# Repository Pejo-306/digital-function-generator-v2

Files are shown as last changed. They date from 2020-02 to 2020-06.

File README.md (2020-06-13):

# Цифров генератор на сигнали с тъчскрийн

Генератор на сигнали, реализиран на принципа на Директния Цифров Синтез (DDS).
Проектът е разработен като дипломна работа в 12-ти клас, ТУЕС.

## Съдържание

* [Кратко описание](#кратко-описание)
* [Документация](#документация)
* [Инсталиране на управляващия софтуер](#инсталиране-на-управляващия-софтуер)
* [Лиценз](#лиценз)

## Кратко описание

Генераторите на сигнали са изключително полезни лабораторни инструменти за
изследване на други електронни устройства или части от тях. Инструментите се
използват за възпроизвеждане на най-различни електрически сигнали, които служат
като входни сигнали за други устройства.

Цифровите генератори на сигнали са mixed-signal устройства (включват и аналогова,
и цифрова схемотехника, като и двете функционират ръка за ръка), реализирани
посредством DDS система. Тези генератори, както и разработеният за тази дипломна
работа, имат следните възможностти:
- възпроизвеждане на сигнали с произволна форма;
- регулиране на амплитудата на сигнали;
- добавяне на постояннотоково отместване към генерирания сигнал;
- настройване на честотата на сигнала.

Освен това разработеното за дипломната работа устройство използва течнокристален
екран с панел за допир за реализиране на потребителския си интерфейс. По-подробно
описание на употребения тъчскрийн модул може да бъде намерено [тук](http://www.lcdwiki.com/3.2inch_SPI_Module_ILI9341_SKU:MSP3218).

## Документация

Подробна документация на дипломната работа, написана на български език, може да
бъде намерена [тук](docs/bg/Diploma%20Work_Petar%20Nikolov_2020-bg.pdf).

## Инсталиране на управляващия софтуер

Управляващият софтуер е написан на езика *AVR-C* и е разработен за
микроконтролери от серията *ATmega2561*. Освен това софтуерният проект се 
управлява с конзолната програма **make**.

Първоначално е необходимо да се дръпне проекта от GitHub и да се навигира
до папката, съдържаща софтуерния проект:

```bash
$ git clone https://github.com/Pejo-306/digital-function-generator-v2.git
$ cd digital-function-generator-v2/software/DFGv2-Firmware.X/
```

Проектът се компилира с **make** програмата:

```bash
$ make build
```

След това е необходимо да се свърже подходящ програматор към *ATmega2561* и да
се запише управляващата програма в програмната флаш памет на микроконтролера:

```bash
$ make flash
```

Също така е необходимо да се конфигурират определени хардуерни настройки на
*ATmega2561*:

```bash
$ make fuse
```

## Лиценз

Този проект се разпространява с [MIT лиценз](LICENSE).

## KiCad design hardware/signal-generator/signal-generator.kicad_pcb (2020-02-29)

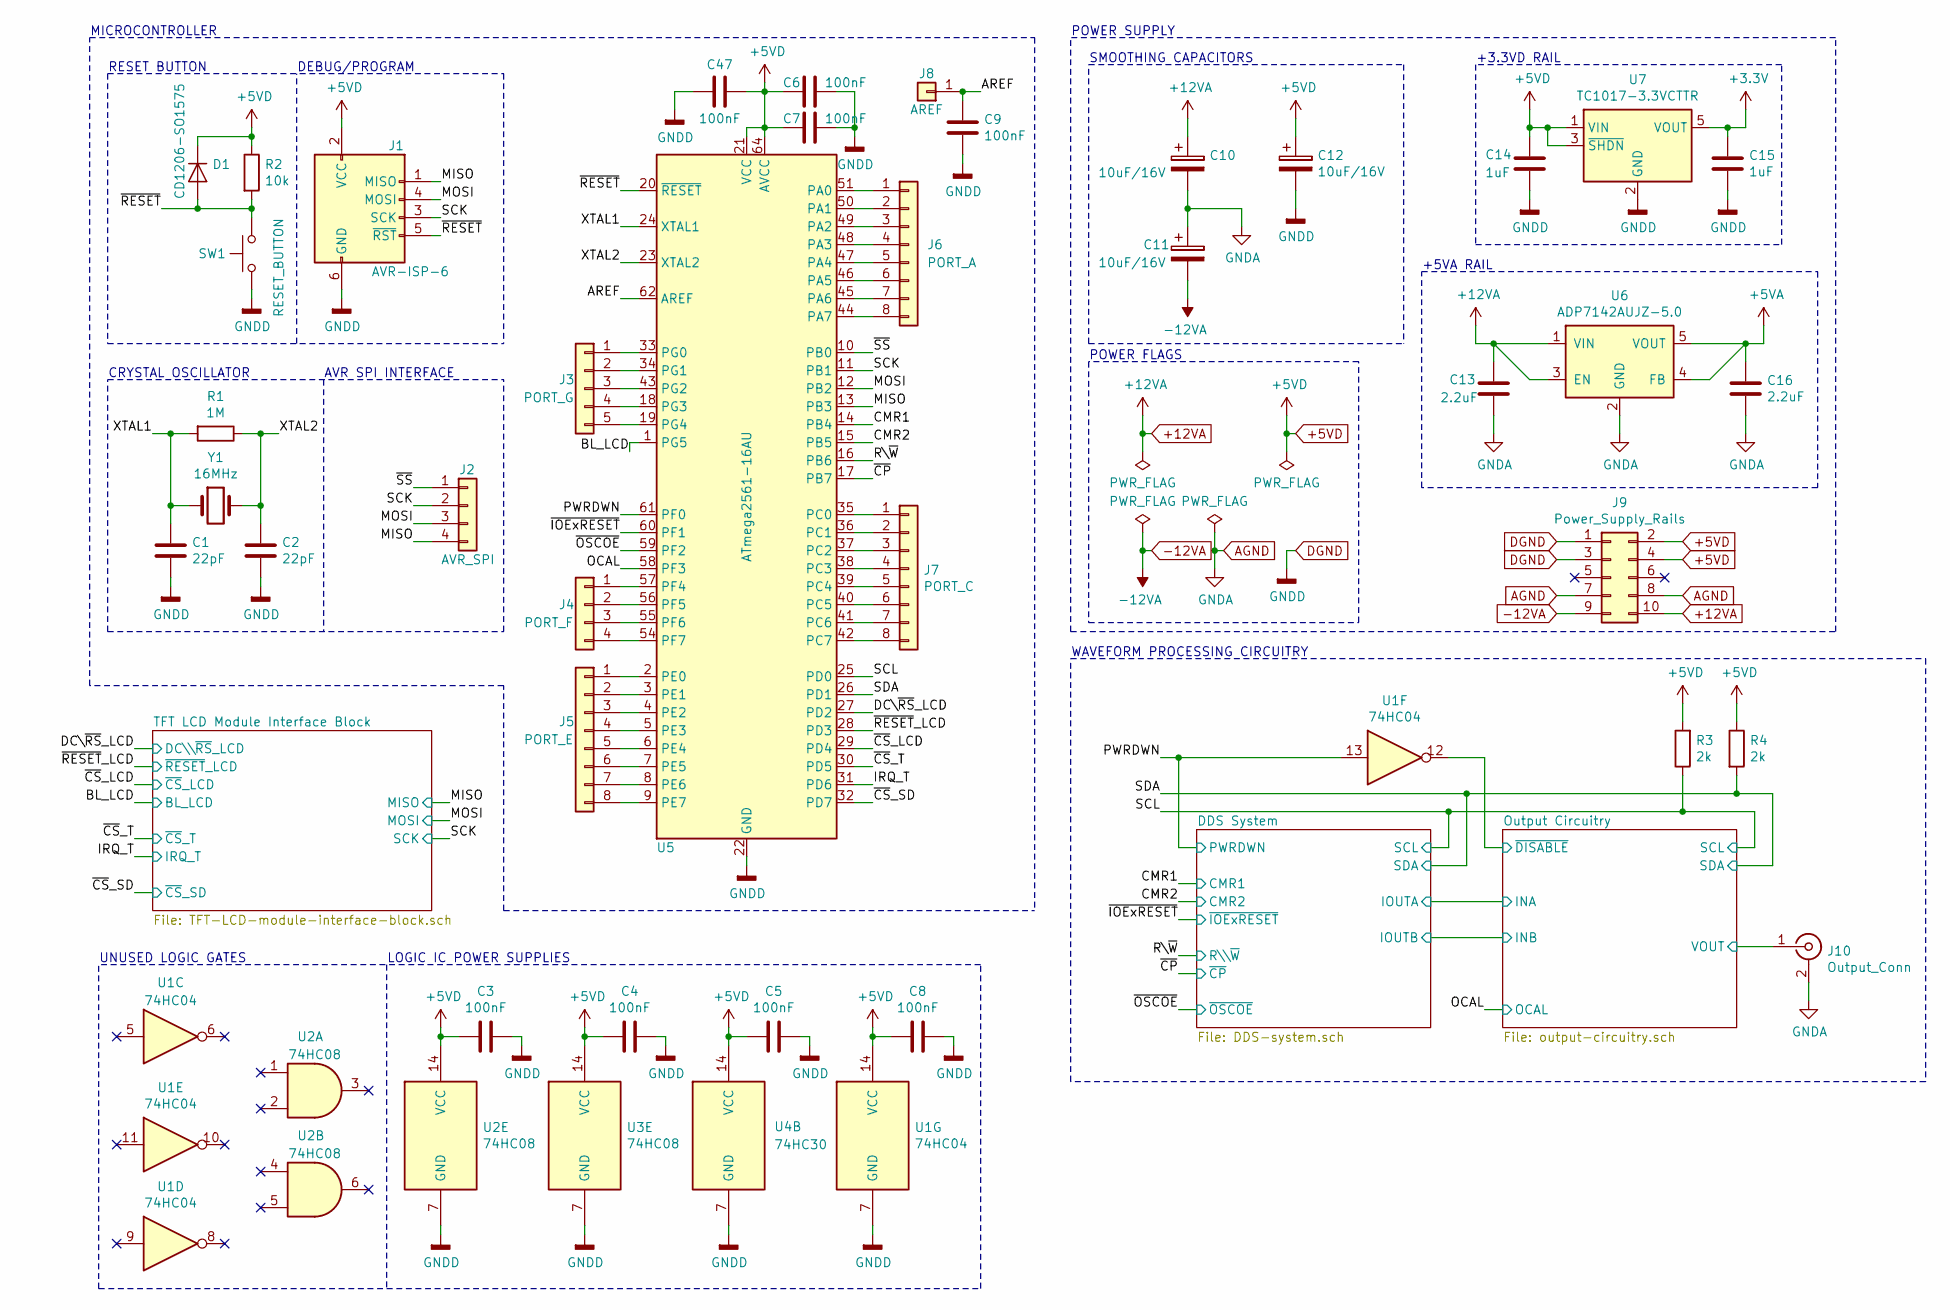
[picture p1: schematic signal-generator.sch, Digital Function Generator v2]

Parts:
C1, C2: 22pF; C_0805_HandSoldering
C3, C4, C5, C6, C7, C8, C9, C47: 100nF; C_0805_HandSoldering
C10, C11, C12: 10uF/16V; CP_Elec_4x5.3
C13, C16: 2.2uF; C_0805_HandSoldering
C14, C15: 1uF; C_0805_HandSoldering
D1: CD1206-SO1575; D_1206
J1: AVR-ISP-6; Pin_Header_Straight_2x03_Pitch2.54mm
J2: AVR_SPI; Pin_Header_Straight_1x04_Pitch2.54mm
J3: PORT_G; Pin_Header_Straight_1x05_Pitch2.54mm
J4: PORT_F; Pin_Header_Straight_1x04_Pitch2.54mm
J5: PORT_E; Pin_Header_Straight_1x08_Pitch2.54mm
J6: PORT_A; Pin_Header_Straight_1x08_Pitch2.54mm
J7: PORT_C; Pin_Header_Straight_1x08_Pitch2.54mm
J8: AREF; Pin_Header_Straight_1x01_Pitch2.54mm
J9: Power_Supply_Rails; Pin_Header_Straight_2x05_Pitch2.54mm
J10: Output_Conn; BNC_Socket_TYCO-AMP
R1: 1M; R_1206_HandSoldering
R2: 10k; R_0805_HandSoldering
R3, R4: 2k; R_0805_HandSoldering
SW1: RESET_BUTTON; SW_PUSH_6mm_h4.3mm
U1: 74HC04; SOIC-14_3.9x8.7mm_Pitch1.27mm
U2, U3: 74HC08; SOIC-14_3.9x8.7mm_Pitch1.27mm
U4: 74HC30; SOIC-14_3.9x8.7mm_Pitch1.27mm
U5: ATmega2561-16AU; TQFP-64_14x14mm_Pitch0.8mm
U6: ADP7142AUJZ-5.0; TSOT-23-5_HandSoldering
U7: TC1017-3.3VCTTR; SOT-23-5_HandSoldering
Y1: 16MHz; Crystal_HC49-U_Vertical

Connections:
+3V3: C15.1, U7.5 (VOUT); also elsewhere on the board
+5VA: C16.1, U6.4 (FB), U6.5 (VOUT); also elsewhere on the board
+12VA: C10.1, C13.1, J9.10, U6.1 (VIN), U6.3 (EN); also elsewhere on the board
-12VA: C11.2, J9.9; also elsewhere on the board
/AREF: C9.1, J8.1, U5.62 (AREF)
/BL_LCD: U5.1 (PG5); also elsewhere on the board
/DC\~RS~_LCD: U5.27 (PD2); also elsewhere on the board
/IRQ_T: U5.31 (PD6); also elsewhere on the board
/MISO: J1.1 (MISO), J2.4, U5.13 (PB3); also elsewhere on the board
/MOSI: J1.4 (MOSI), J2.3, U5.12 (PB2); also elsewhere on the board
/OCAL: U5.58 (PF3); also elsewhere on the board
/Output Circuitry/VOUT: J10.1 (In); also elsewhere on the board
/Output Circuitry/~DISABLE: U1.12; also elsewhere on the board
/PWRDWN: U1.13, U5.61 (PF0); also elsewhere on the board
/R\~W: U5.16 (PB6); also elsewhere on the board
/SCK: J1.3 (SCK), J2.2, U5.11 (PB1); also elsewhere on the board
/SCL: R3.1, U5.25 (PD0); also elsewhere on the board
/SDA: R4.2, U5.26 (PD1); also elsewhere on the board
/XTAL1: C1.1, R1.2, U5.24 (XTAL1), Y1.1
/XTAL2: C2.1, R1.1, U5.23 (XTAL2), Y1.2
/~CMR1: U5.14 (PB4); also elsewhere on the board
/~CMR2: U5.15 (PB5); also elsewhere on the board
/~CP: U5.17 (PB7); also elsewhere on the board
/~CS~_LCD: U5.29 (PD4); also elsewhere on the board
/~CS~_SD: U5.32 (PD7); also elsewhere on the board
/~CS~_T: U5.30 (PD5); also elsewhere on the board
/~IOExRESET: U5.60 (PF1); also elsewhere on the board
/~OSCOE: U5.59 (PF2); also elsewhere on the board
/~RESET: D1.2 (A), J1.5 (~RST), R2.2, SW1.2, U5.20 (~RESET)
/~RESET~_LCD: U5.28 (PD3); also elsewhere on the board
/~SS: J2.1, U5.10 (PB0)
unnamed: J3.1, U5.33 (PG0)
unnamed: J3.2, U5.34 (PG1)
unnamed: J3.3, U5.43 (PG2)
unnamed: J3.4, U5.18 (PG3)
unnamed: J3.5, U5.19 (PG4)
unnamed: J4.1, U5.57 (PF4)
unnamed: J4.2, U5.56 (PF5)
unnamed: J4.3, U5.55 (PF6)
unnamed: J4.4, U5.54 (PF7)
unnamed: J5.1, U5.2 (PE0)
unnamed: J5.2, U5.3 (PE1)
unnamed: J5.3, U5.4 (PE2)
unnamed: J5.4, U5.5 (PE3)
unnamed: J5.5, U5.6 (PE4)
unnamed: J5.6, U5.7 (PE5)
unnamed: J5.7, U5.8 (PE6)
unnamed: J5.8, U5.9 (PE7)
unnamed: J6.1, U5.51 (PA0)
unnamed: J6.2, U5.50 (PA1)
unnamed: J6.3, U5.49 (PA2)
unnamed: J6.4, U5.48 (PA3)
unnamed: J6.5, U5.47 (PA4)
unnamed: J6.6, U5.46 (PA5)
unnamed: J6.7, U5.45 (PA6)
unnamed: J6.8, U5.44 (PA7)
unnamed: J7.1, U5.35 (PC0)
unnamed: J7.2, U5.36 (PC1)
unnamed: J7.3, U5.37 (PC2)
unnamed: J7.4, U5.38 (PC3)
unnamed: J7.5, U5.39 (PC4)
unnamed: J7.6, U5.40 (PC5)
unnamed: J7.7, U5.41 (PC6)
unnamed: J7.8, U5.42 (PC7)

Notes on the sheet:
POWER FLAGS
SMOOTHING CAPACITORS
+5VA RAIL
POWER SUPPLY
RESET BUTTON
DEBUG/PROGRAM
CRYSTAL OSCILLATOR
+3.3VD RAIL
AVR SPI INTERFACE
MICROCONTROLLER
WAVEFORM PROCESSING CIRCUITRY
LOGIC IC POWER SUPPLIES
UNUSED LOGIC GATES

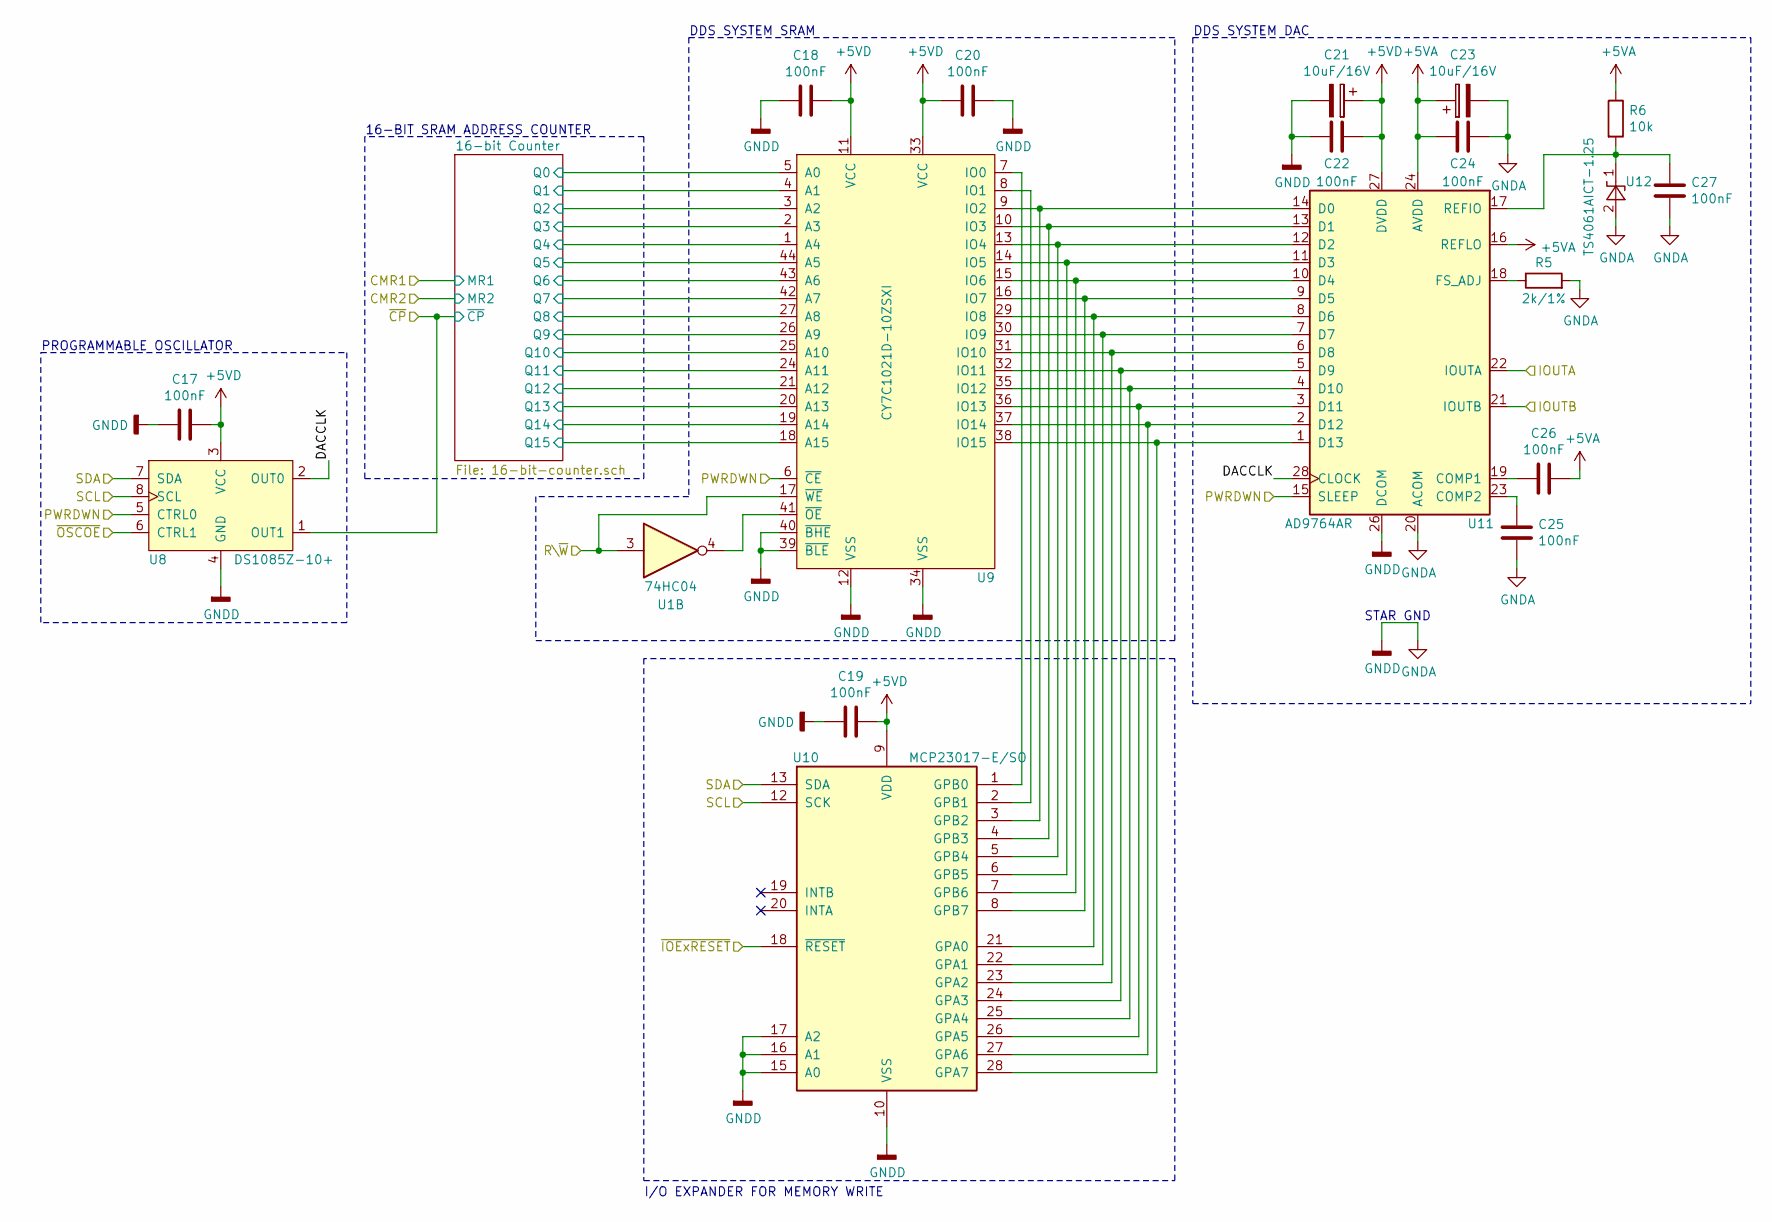
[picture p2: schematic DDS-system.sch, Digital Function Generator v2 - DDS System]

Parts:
C17, C18, C19, C20, C22, C24, C25, C26, C27: 100nF; C_0805_HandSoldering
C21, C23: 10uF/16V; CP_Tantalum_Case-A_EIA-3216-18_Hand
R5: 2k/1%; R_0805_HandSoldering
R6: 10k; R_0805_HandSoldering
U1: 74HC04; SOIC-14_3.9x8.7mm_Pitch1.27mm
U8: DS1085Z-10+; SOIC-8_3.9x4.9mm_Pitch1.27mm
U9: CY7C1021D-10ZSXI; SOP80P1176X120-44N
U10: MCP23017-E/SO; SOIC-28W_7.5x17.9mm_Pitch1.27mm
U11: AD9764AR; SOIC-28W_7.5x17.9mm_Pitch1.27mm
U12: TS4061AICT-1.25; SOT-323_SC-70_Handsoldering

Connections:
+5VA: C23.1, C24.2, C26.1, R6.1, U11.16 (REFLO), U11.24 (AVDD); also elsewhere on the board
/DDS System/16-bit Counter/Q0: U9.5 (A0); also elsewhere on the board
/DDS System/16-bit Counter/Q1: U9.4 (A1); also elsewhere on the board
/DDS System/16-bit Counter/Q2: U9.3 (A2); also elsewhere on the board
/DDS System/16-bit Counter/Q3: U9.2 (A3); also elsewhere on the board
/DDS System/16-bit Counter/Q4: U9.1 (A4); also elsewhere on the board
/DDS System/16-bit Counter/Q5: U9.44 (A5); also elsewhere on the board
/DDS System/16-bit Counter/Q6: U9.43 (A6); also elsewhere on the board
/DDS System/16-bit Counter/Q7: U9.42 (A7); also elsewhere on the board
/DDS System/16-bit Counter/Q8: U9.27 (A8); also elsewhere on the board
/DDS System/16-bit Counter/Q9: U9.26 (A9); also elsewhere on the board
/DDS System/16-bit Counter/Q10: U9.25 (A10); also elsewhere on the board
/DDS System/16-bit Counter/Q11: U9.24 (A11); also elsewhere on the board
/DDS System/16-bit Counter/Q12: U9.21 (A12); also elsewhere on the board
/DDS System/16-bit Counter/Q13: U9.20 (A13); also elsewhere on the board
/DDS System/16-bit Counter/Q14: U9.19 (A14); also elsewhere on the board
/DDS System/16-bit Counter/Q15: U9.18 (A15); also elsewhere on the board
/DDS System/DACCLK: U8.2 (OUT0), U11.28 (CLOCK)
/Output Circuitry/INA: U11.22 (IOUTA); also elsewhere on the board
/Output Circuitry/INB: U11.21 (IOUTB); also elsewhere on the board
/PWRDWN: U8.5 (CTRL0), U9.6 (~CE), U11.15 (SLEEP); also elsewhere on the board
/R\~W: U1.3, U9.17 (~WE); also elsewhere on the board
/SCL: U8.8 (SCL), U10.12 (SCK); also elsewhere on the board
/SDA: U8.7 (SDA), U10.13 (SDA); also elsewhere on the board
/~CP: U8.1 (OUT1); also elsewhere on the board
/~IOExRESET: U10.18 (~RESET~); also elsewhere on the board
/~OSCOE: U8.6 (CTRL1); also elsewhere on the board
unnamed: C25.2, U11.23 (COMP2)
unnamed: C26.2, U11.19 (COMP1)
unnamed: C27.1, R6.2, U11.17 (REFIO), U12.1 (K)
unnamed: R5.1, U11.18 (FS_ADJ)
unnamed: U1.4, U9.41 (~OE)
unnamed: U9.7 (IO0), U10.1 (GPB0)
unnamed: U9.8 (IO1), U10.2 (GPB1)
unnamed: U9.9 (IO2), U10.3 (GPB2), U11.14 (D0)
unnamed: U9.10 (IO3), U10.4 (GPB3), U11.13 (D1)
unnamed: U9.13 (IO4), U10.5 (GPB4), U11.12 (D2)
unnamed: U9.14 (IO5), U10.6 (GPB5), U11.11 (D3)
unnamed: U9.15 (IO6), U10.7 (GPB6), U11.10 (D4)
unnamed: U9.16 (IO7), U10.8 (GPB7), U11.9 (D5)
unnamed: U9.29 (IO8), U10.21 (GPA0), U11.8 (D6)
unnamed: U9.30 (IO9), U10.22 (GPA1), U11.7 (D7)
unnamed: U9.31 (IO10), U10.23 (GPA2), U11.6 (D8)
unnamed: U9.32 (IO11), U10.24 (GPA3), U11.5 (D9)
unnamed: U9.35 (IO12), U10.25 (GPA4), U11.4 (D10)
unnamed: U9.36 (IO13), U10.26 (GPA5), U11.3 (D11)
unnamed: U9.37 (IO14), U10.27 (GPA6), U11.2 (D12)
unnamed: U9.38 (IO15), U10.28 (GPA7), U11.1 (D13)

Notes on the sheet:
STAR GND
PROGRAMMABLE OSCILLATOR
I/O EXPANDER FOR MEMORY WRITE
16-BIT SRAM ADDRESS COUNTER
DDS SYSTEM SRAM
DDS SYSTEM DAC

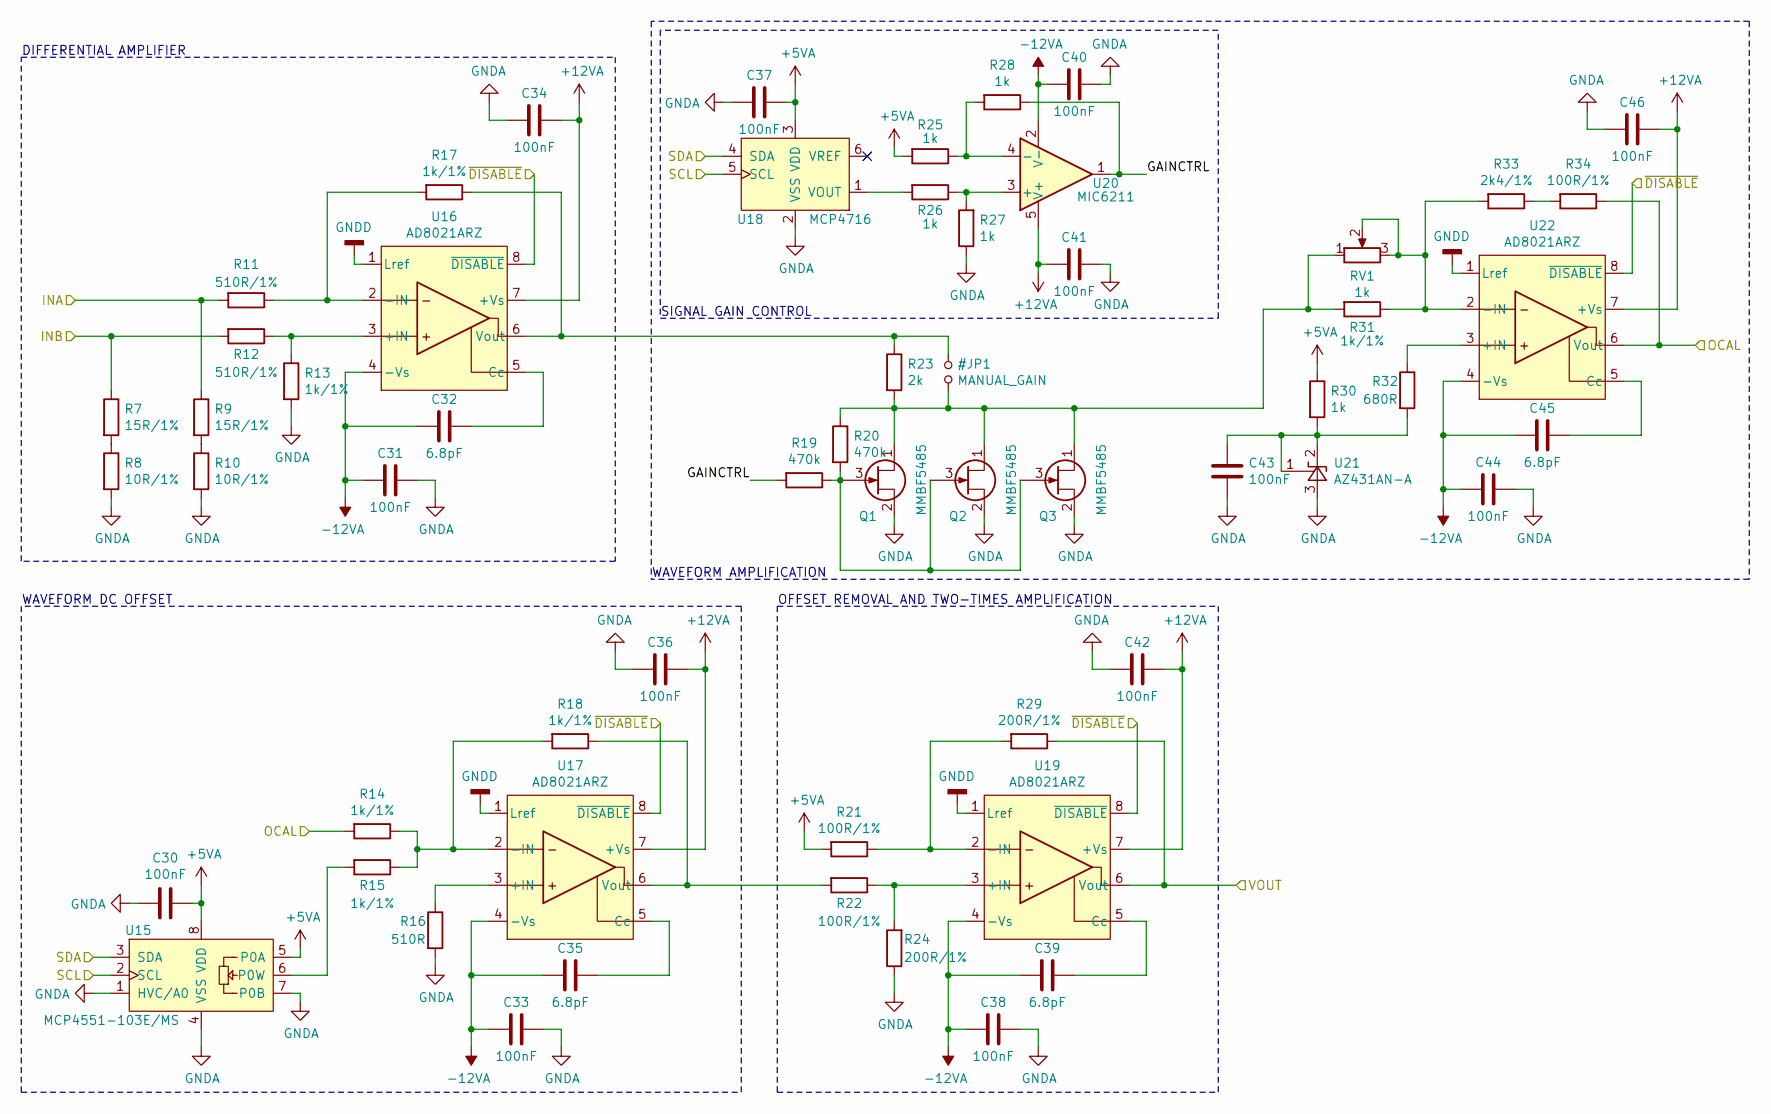
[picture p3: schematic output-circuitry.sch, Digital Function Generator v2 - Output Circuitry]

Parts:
C30, C31, C33, C34, C36, C37, C38, C40, C41, C42, C43, C44, C46: 100nF; C_0805_HandSoldering
C32, C35, C39, C45: 6.8pF; C_0805_HandSoldering
Q1, Q2, Q3: MMBF5485; SOT-23_Handsoldering
R7, R9: 15R/1%; R_0805_HandSoldering
R8, R10: 10R/1%; R_0805_HandSoldering
R11, R12: 510R/1%; R_0805_HandSoldering
R13, R14, R15, R17, R18, R31: 1k/1%; R_0805_HandSoldering
R16: 510R; R_0805_HandSoldering
R19, R20: 470k; R_0805_HandSoldering
R21, R22, R34: 100R/1%; R_0805_HandSoldering
R23: 2k; R_0805_HandSoldering
R24, R29: 200R/1%; R_0805_HandSoldering
R25, R26, R27, R28, R30: 1k; R_0805_HandSoldering
R32: 680R; R_0805_HandSoldering
R33: 2k4/1%; R_0805_HandSoldering
RV1: 1k; Potentiometer_Alps_RK163_Single_Vertical
U15: MCP4551-103E/MS; MSOP-8_3x3mm_Pitch0.65mm
U16, U17, U19, U22: AD8021ARZ; SOIC-8_3.9x4.9mm_Pitch1.27mm
U18: MCP4716; SOT-23-6_Handsoldering
U20: MIC6211; SOT-23-5_HandSoldering
U21: AZ431AN-A; SOT-23_Handsoldering

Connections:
+5VA: C30.1, C37.1, R21.2, R25.2, R30.1, U15.5 (P0A), U15.8 (VDD), U18.3 (VDD); also elsewhere on the board
+12VA: C34.1, C36.1, C41.2, C42.1, C46.1, U16.7 (+Vs), U17.7 (+Vs), U19.7 (+Vs), U20.5 (V+), U22.7 (+Vs); also elsewhere on the board
-12VA: C31.2, C32.2, C33.2, C35.2, C38.2, C39.2, C40.2, C44.2, C45.2, U16.4 (-Vs), U17.4 (-Vs), U19.4 (-Vs), U20.2 (V-), U22.4 (-Vs); also elsewhere on the board
/OCAL: R14.2, R34.1, U22.6 (Vout); also elsewhere on the board
/Output Circuitry/GAINCTRL: R19.2, R28.1, U20.1
/Output Circuitry/INA: R9.1, R11.2; also elsewhere on the board
/Output Circuitry/INB: R7.1, R12.2; also elsewhere on the board
/Output Circuitry/VOUT: R29.1, U19.6 (Vout); also elsewhere on the board
/Output Circuitry/~DISABLE: U16.8 (~DISABLE), U17.8 (~DISABLE), U19.8 (~DISABLE), U22.8 (~DISABLE); also elsewhere on the board
/SCL: U15.2 (SCL), U18.5 (SCL); also elsewhere on the board
/SDA: U15.3 (SDA), U18.4 (SDA); also elsewhere on the board
unnamed: C32.1, U16.5 (Cc)
unnamed: C35.1, U17.5 (Cc)
unnamed: C39.1, U19.5 (Cc)
unnamed: C43.1, R30.2, R32.2, U21.1 (REF), U21.2 (K)
unnamed: C45.1, U22.5 (Cc)
unnamed: Q1.3 (G), Q2.3 (G), Q3.3 (G), R19.1, R20.2
unnamed: R7.2, R8.1
unnamed: R9.2, R10.1
unnamed: R11.1, R17.2, U16.2 (-IN)
unnamed: R12.1, R13.1, U16.3 (+IN)
unnamed: R14.1, R15.1, R18.2, U17.2 (-IN)
unnamed: R15.2, U15.6 (P0W)
unnamed: R16.1, U17.3 (+IN)
unnamed: R18.1, R22.2, U17.6 (Vout)
unnamed: R21.1, R29.2, U19.2 (-IN)
unnamed: R22.1, R24.2, U19.3 (+IN)
unnamed: R25.1, R28.2, U20.4 (-)
unnamed: R26.1, R27.2, U20.3 (+)
unnamed: R26.2, U18.1 (VOUT)
unnamed: R31.1, R33.2, RV1.2, RV1.3, U22.2 (-IN)
unnamed: R32.1, U22.3 (+IN)
unnamed: R33.1, R34.2

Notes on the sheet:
DIFFERENTIAL AMPLIFIER
OFFSET REMOVAL AND TWO-TIMES AMPLIFICATION
WAVEFORM DC OFFSET
SIGNAL GAIN CONTROL
WAVEFORM AMPLIFICATION

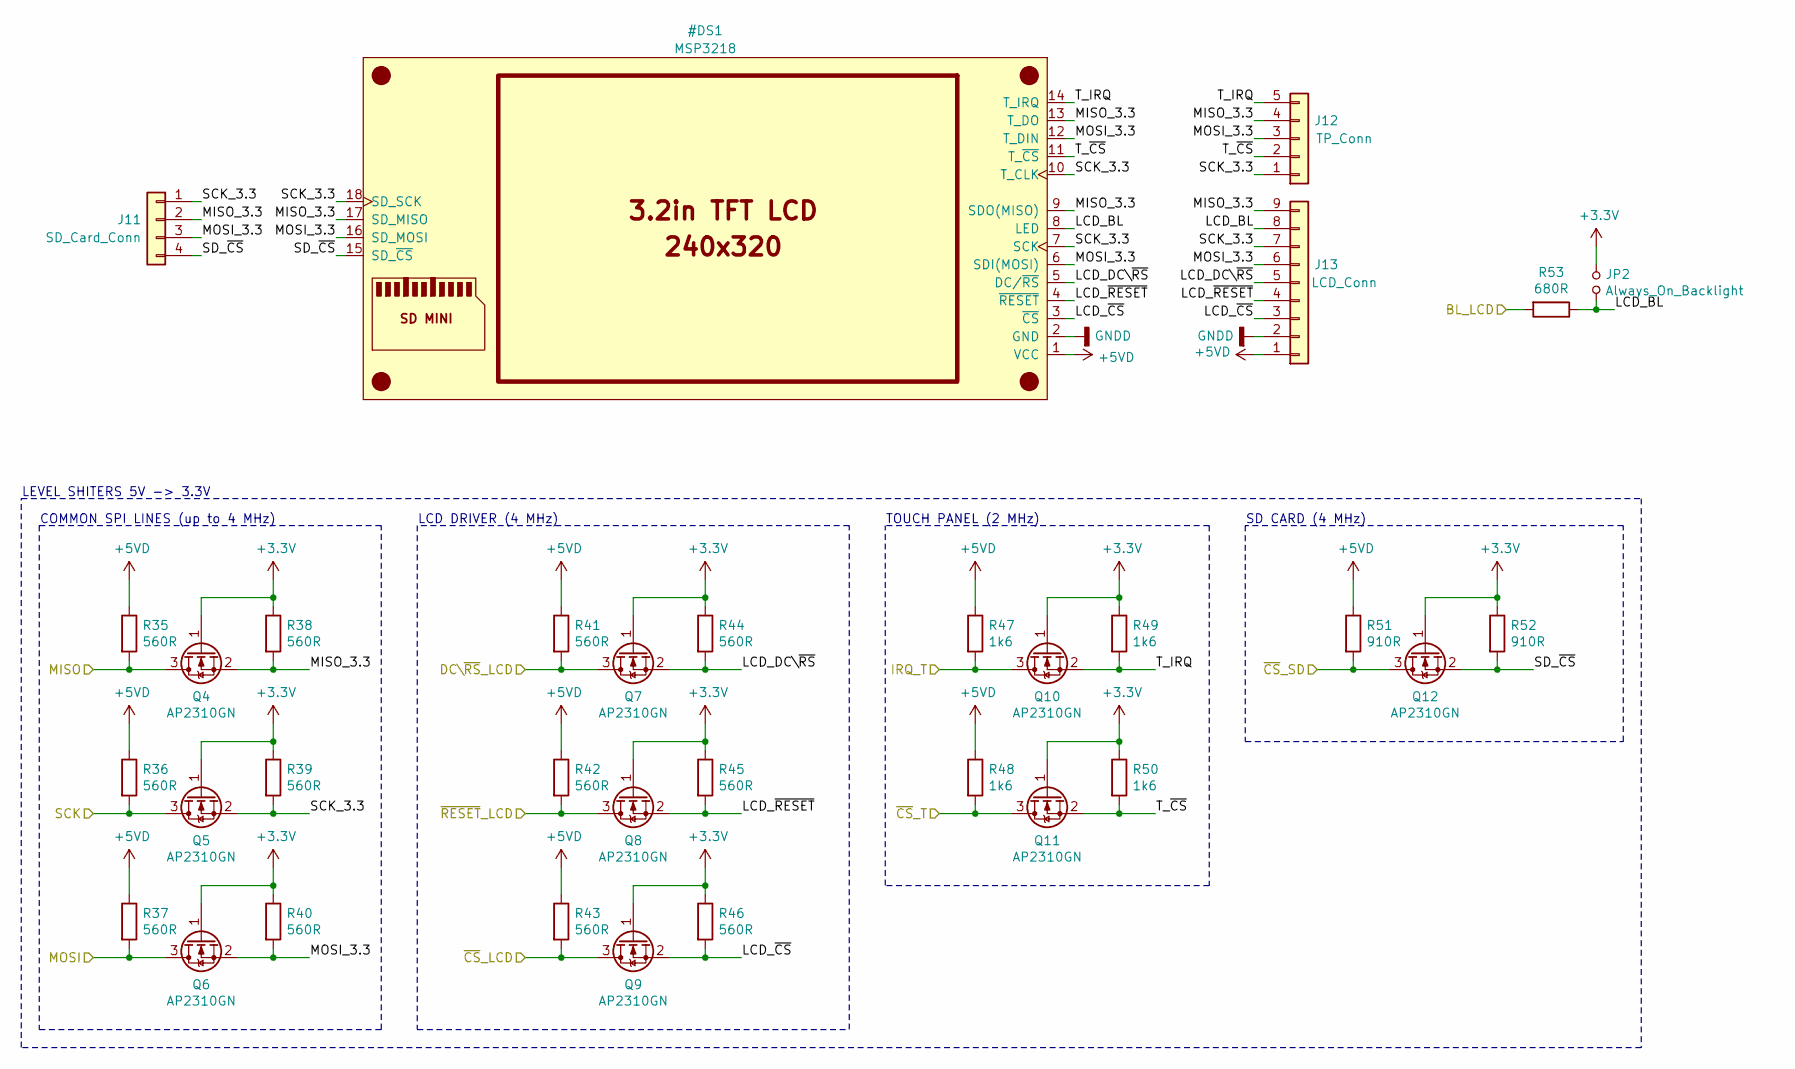
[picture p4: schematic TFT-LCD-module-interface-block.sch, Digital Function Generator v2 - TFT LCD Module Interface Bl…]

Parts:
J11: SD_Card_Conn; Pin_Header_Straight_1x04_Pitch2.54mm
J12: TP_Conn; Pin_Header_Straight_1x05_Pitch2.54mm
J13: LCD_Conn; Pin_Header_Straight_1x09_Pitch2.54mm
JP2: Always_On_Backlight; Pin_Header_Straight_1x02_Pitch2.54mm
Q4, Q5, Q6, Q7, Q8, Q9, Q10, Q11, Q12: AP2310GN; SOT-23_Handsoldering
R35, R36, R37, R38, R39, R40, R41, R42, R43, R44, R45, R46: 560R; R_0805_HandSoldering
R47, R48, R49, R50: 1k6; R_0805_HandSoldering
R51, R52: 910R; R_0805_HandSoldering
R53: 680R; R_0805_HandSoldering

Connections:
+3V3: JP2.1, Q4.1, Q5.1, Q6.1, Q7.1, Q8.1, Q9.1, Q10.1, Q11.1, Q12.1, R38.1, R39.1, R40.1, R44.1, R45.1, R46.1, R49.1, R50.1, R52.1; also elsewhere on the board
/BL_LCD: R53.2; also elsewhere on the board
/DC\~RS~_LCD: Q7.3, R41.2; also elsewhere on the board
/IRQ_T: Q10.3, R47.2; also elsewhere on the board
/MISO: Q4.3, R35.2; also elsewhere on the board
/MOSI: Q6.3, R37.2; also elsewhere on the board
/SCK: Q5.3, R36.2; also elsewhere on the board
/~CS~_LCD: Q9.3, R43.2; also elsewhere on the board
/~CS~_SD: Q12.3, R51.2; also elsewhere on the board
/~CS~_T: Q11.3, R48.2; also elsewhere on the board
/~RESET~_LCD: Q8.3, R42.2; also elsewhere on the board

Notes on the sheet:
TOUCH PANEL (2 MHz)
LCD DRIVER (4 MHz)
COMMON SPI LINES (up to 4 MHz)
LEVEL SHITERS 5V -> 3.3V
SD CARD (4 MHz)

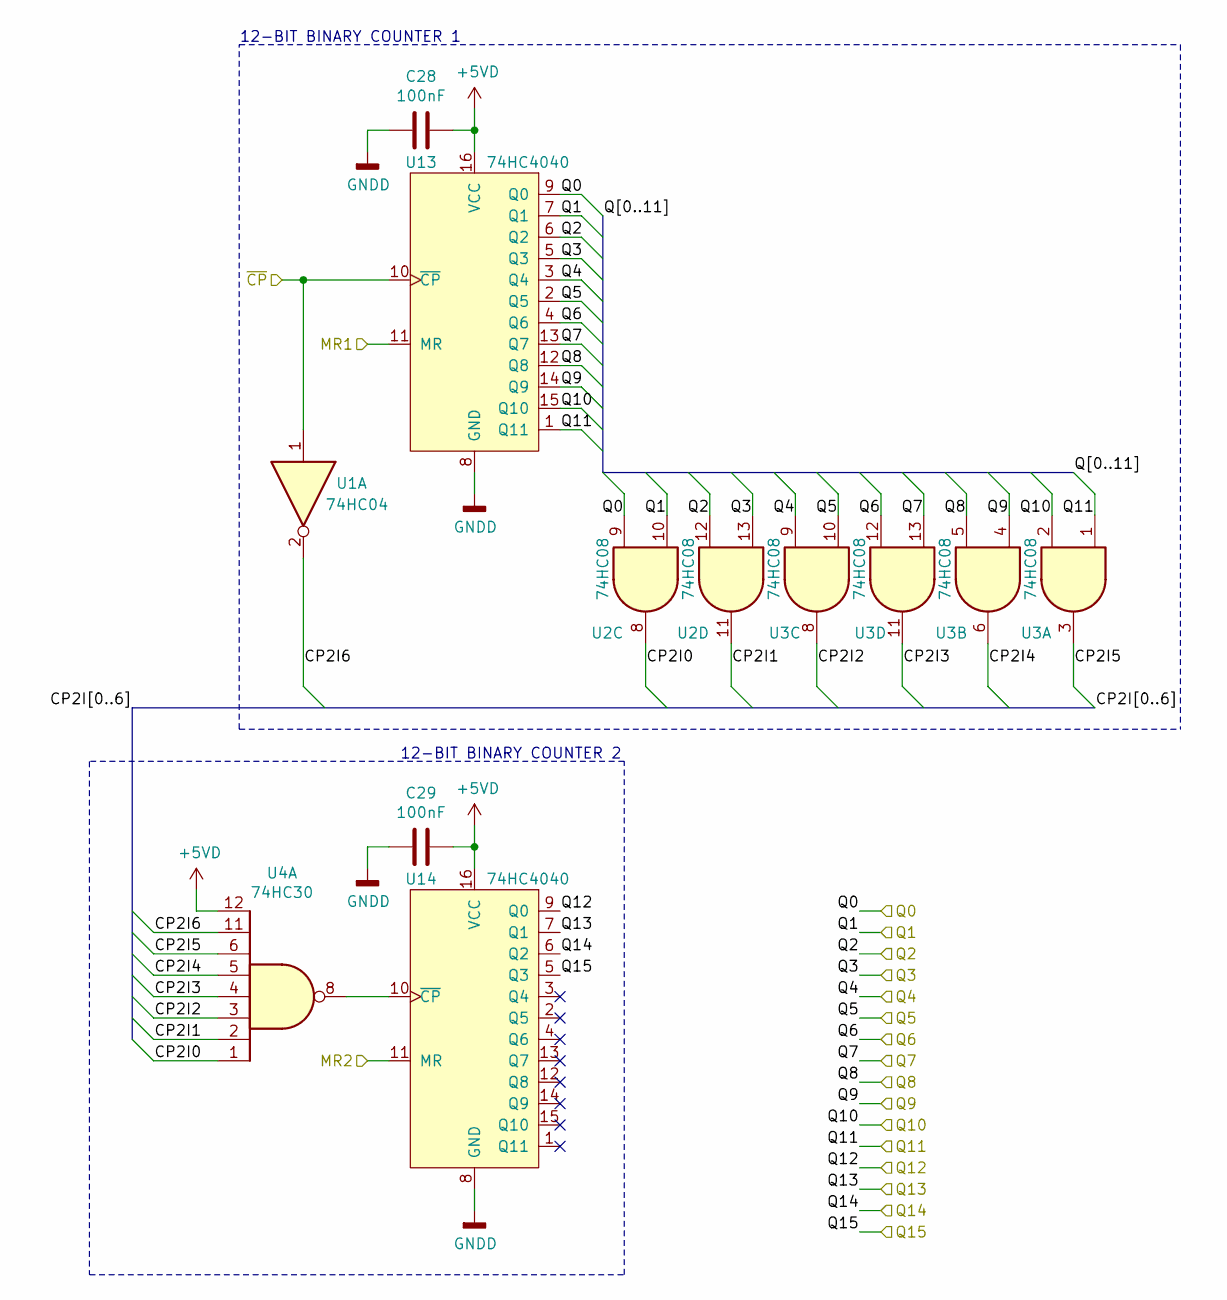
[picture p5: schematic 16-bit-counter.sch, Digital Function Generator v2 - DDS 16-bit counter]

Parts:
C28, C29: 100nF; C_0805_HandSoldering
U1: 74HC04; SOIC-14_3.9x8.7mm_Pitch1.27mm
U2, U3: 74HC08; SOIC-14_3.9x8.7mm_Pitch1.27mm
U4: 74HC30; SOIC-14_3.9x8.7mm_Pitch1.27mm
U13, U14: 74HC4040; SOIC-16_3.9x9.9mm_Pitch1.27mm

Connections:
/DDS System/16-bit Counter/CP2I0: U2.8, U4.1
/DDS System/16-bit Counter/CP2I1: U2.11, U4.2
/DDS System/16-bit Counter/CP2I2: U3.8, U4.3
/DDS System/16-bit Counter/CP2I3: U3.11, U4.4
/DDS System/16-bit Counter/CP2I4: U3.6, U4.5
/DDS System/16-bit Counter/CP2I5: U3.3, U4.6
/DDS System/16-bit Counter/CP2I6: U1.2, U4.11
/DDS System/16-bit Counter/Q0: U2.9, U13.9 (Q0); also elsewhere on the board
/DDS System/16-bit Counter/Q1: U2.10, U13.7 (Q1); also elsewhere on the board
/DDS System/16-bit Counter/Q2: U2.12, U13.6 (Q2); also elsewhere on the board
/DDS System/16-bit Counter/Q3: U2.13, U13.5 (Q3); also elsewhere on the board
/DDS System/16-bit Counter/Q4: U3.9, U13.3 (Q4); also elsewhere on the board
/DDS System/16-bit Counter/Q5: U3.10, U13.2 (Q5); also elsewhere on the board
/DDS System/16-bit Counter/Q6: U3.12, U13.4 (Q6); also elsewhere on the board
/DDS System/16-bit Counter/Q7: U3.13, U13.13 (Q7); also elsewhere on the board
/DDS System/16-bit Counter/Q8: U3.5, U13.12 (Q8); also elsewhere on the board
/DDS System/16-bit Counter/Q9: U3.4, U13.14 (Q9); also elsewhere on the board
/DDS System/16-bit Counter/Q10: U3.2, U13.15 (Q10); also elsewhere on the board
/DDS System/16-bit Counter/Q11: U3.1, U13.1 (Q11); also elsewhere on the board
/DDS System/16-bit Counter/Q12: U14.9 (Q0); also elsewhere on the board
/DDS System/16-bit Counter/Q13: U14.7 (Q1); also elsewhere on the board
/DDS System/16-bit Counter/Q14: U14.6 (Q2); also elsewhere on the board
/DDS System/16-bit Counter/Q15: U14.5 (Q3); also elsewhere on the board
/~CMR1: U13.11 (MR); also elsewhere on the board
/~CMR2: U14.11 (MR); also elsewhere on the board
/~CP: U1.1, U13.10 (~CP); also elsewhere on the board
unnamed: U4.8, U14.10 (~CP)

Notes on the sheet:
12-BIT BINARY COUNTER 1
12-BIT BINARY COUNTER 2

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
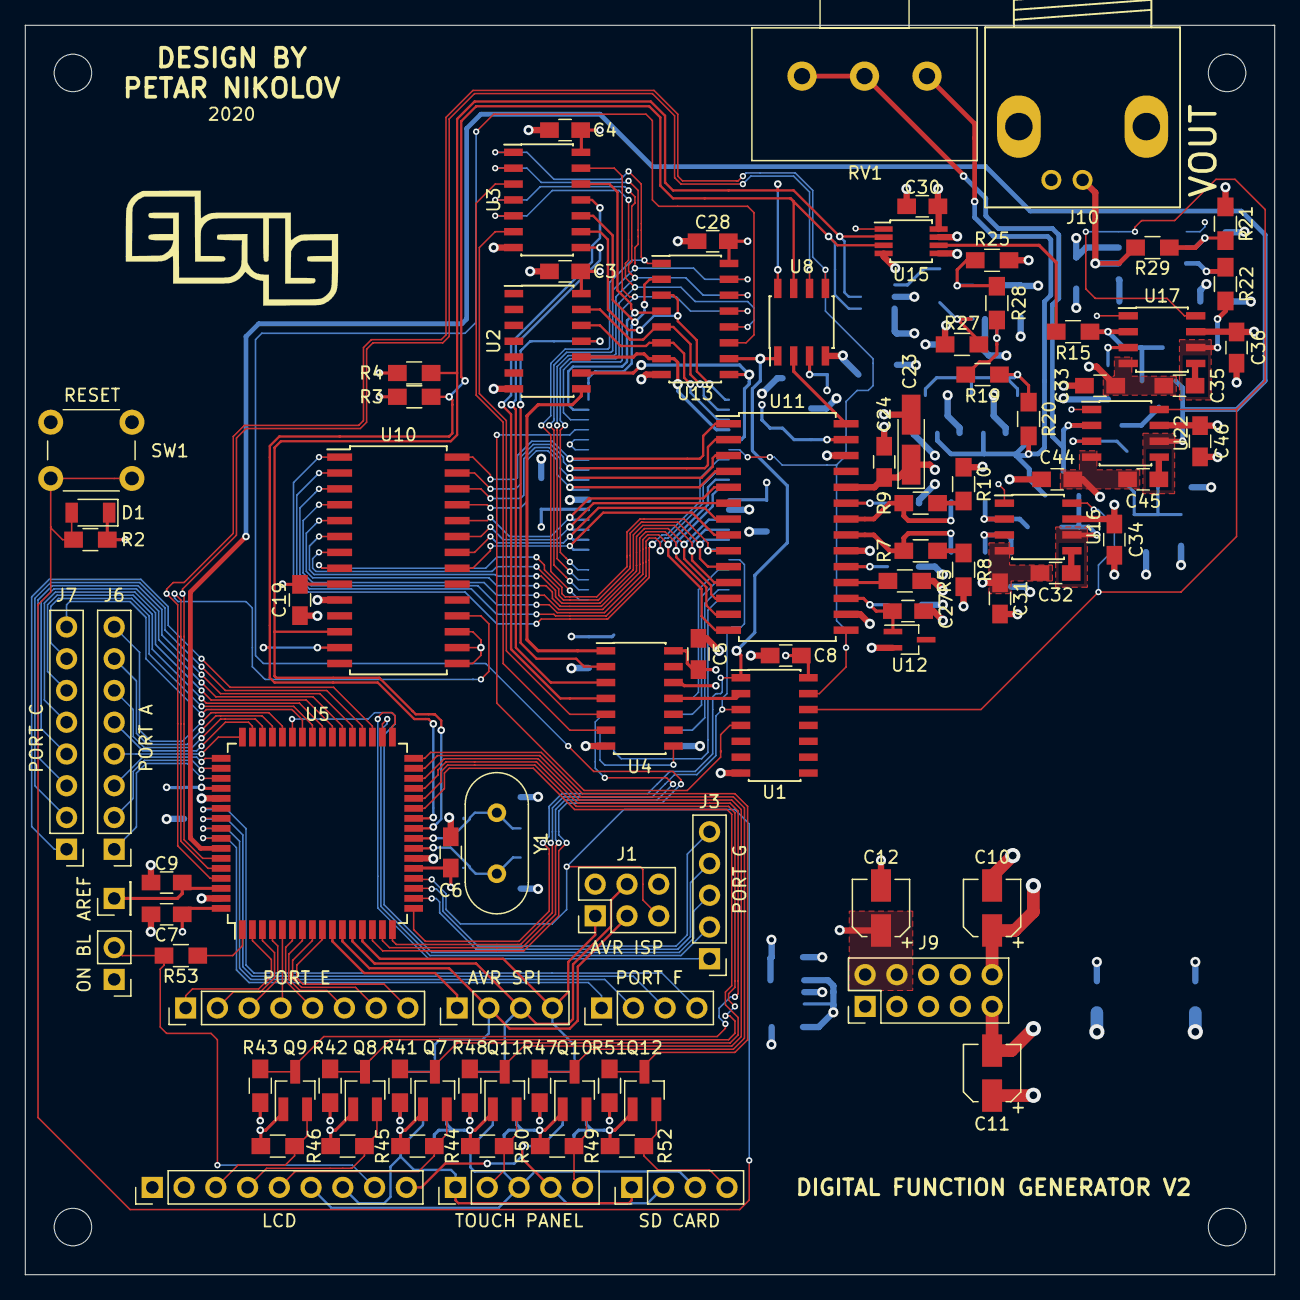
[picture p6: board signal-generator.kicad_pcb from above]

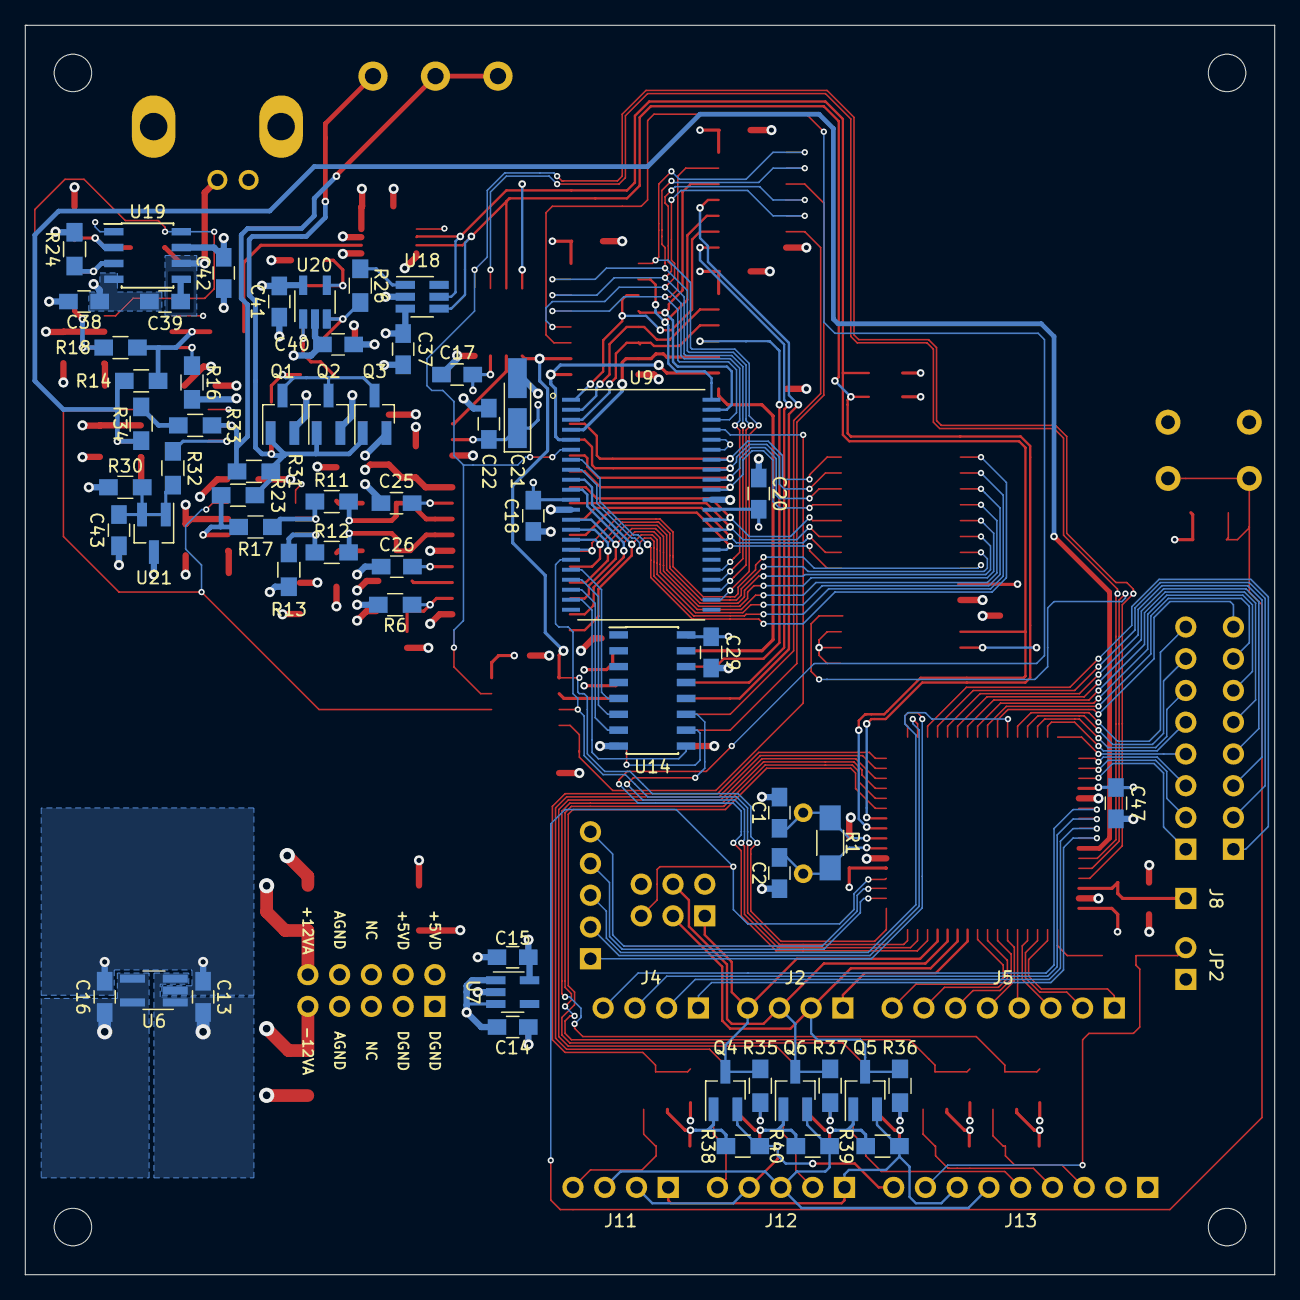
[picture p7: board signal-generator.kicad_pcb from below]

Board: 4 copper layers, 99.9 x 99.9 mm, 152 parts (59 on the bottom side), 149 nets.

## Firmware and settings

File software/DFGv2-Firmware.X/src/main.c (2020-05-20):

/*
 * File:   main.c
 * Author: pesho
 *
 * Created on January 25, 2020, 6:47 PM
 */

#include <util/delay.h>

#include "defs.h"
#include "init_mcu.h"
#include "avr_controllers/twi_controller.h"
#include "avr_controllers/spi_controller.h"
#include "lcd-driver/lcd-driver.h"
#include "touch-panel-driver/touch-panel-driver.h"
#include "user-interface/ui_helper.h"
#include "user-interface/ui_main_menu.h"
#include "user-interface/ui_options_menu.h"
#include "DFG-firmware/DDS_firmware.h"
#include "DFG-firmware/IOexpander_driver.h"
#include "DFG-firmware/programmable_oscillator_driver.h"

int main(void)
{       
    // initialize MCU
    init_mcu();
    twi_init();
    twi_set_speed(TWI_400KHZ, 0);
    twi_set_slave_address(0x00);
    
    // reset MCP23017
    ioex_reset();

    // initialize programmable oscillator (DS1085)
    osc_conf_mux_word(U8_TWI_ADDRESS, 0x2000);
    osc_output_disable();
    
    // initialize offset potentiometer
    set_dc_offset(0x80);
    
    // initialize touchscreen module
    struct spi_interface_t spi = { &DDRB, PB1, PB3, PB2 };
    struct touch_driver_t touch = { &spi, tcs_pin, tirq_pin };
    touch_driver_init(&touch, 0);
    struct lcd_driver_t driver = { &spi, dcx_pin, reset_pin, csx_pin };
    lcd_driver_init(&driver, FBOOL0);
    lcd_reset(&driver);
    _delay_ms(200);
    lcd_power_on(&driver);
    lcd_memory_access_control(&driver, MADCTL_MV | MADCTL_BGR);
    
    uint16_t x, y;
    enum menu_scene selected_menu_scene = NONE;
    void (*draw_menu_p)(struct lcd_driver_t *);
    void (*scan_menu_p)(struct lcd_driver_t *, uint16_t, uint16_t);
    while (1) {
        if (g_current_menu_scene != selected_menu_scene) {
            switch (g_current_menu_scene) {
            case MAIN_MENU:
                draw_menu_p = &draw_main_menu;
                scan_menu_p = &scan_main_menu;
                break;
            case OPTIONS_MENU:
                draw_menu_p = &draw_options_menu;
                scan_menu_p = &scan_options_menu;
                break;
            default:
                break;
            }
            selected_menu_scene = g_current_menu_scene;
            spi_set_speed(SPI_4MHZ);  // 4 MHz
            (*draw_menu_p)(&driver);
        }
        
        spi_set_speed(SPI_2MHZ);  // 2 MHz
        if (touch_scan(&touch, &x, &y)) {
            touch_get_screen_coordinates(&driver, &x, &y);
        } else {
            x = 0xFFFF;
            y = 0xFFFF;
        }
        spi_set_speed(SPI_4MHZ);  // 4 MHz
        (*scan_menu_p)(&driver, x, y);
    }
}

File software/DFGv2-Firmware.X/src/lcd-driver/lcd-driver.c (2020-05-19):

#include "lcd-driver/lcd-driver.h"

#include <avr/pgmspace.h>
#include <util/delay.h>
#include <inttypes.h>

#include "defs.h"
#include "lcd-driver/lcd-driver-chip.h"
#include "avr_controllers/spi_controller.h"

static void _lcd_command_no_parameter(struct lcd_driver_t *, uint8_t);

static uint8_t _lcd_command_read_single_byte(struct lcd_driver_t *, 
        uint8_t);

static void _lcd_command_read_data(struct lcd_driver_t *, 
        uint8_t, uint8_t *, short);

static void _lcd_write_command(struct lcd_driver_t *, uint8_t, uint8_t *, short);

void lcd_driver_init(struct lcd_driver_t *driver, fbool options)
{
    /* fbool options:
     * bit 0: initialize Master SPI
     * bits 1-7: not used
     */
    // optionally initialize the SPI interface
    if (options & FBOOL0)
        mspi_init(driver->spi);

    driver->madctl = MADCTL_DEFAULT_VALUE;
    driver->res_x = (driver->madctl & MADCTL_MV) ? LCD_RESY : LCD_RESX;
    driver->res_y = (driver->madctl & MADCTL_MV) ? LCD_RESX : LCD_RESY;
    _dcx_data(driver);
    _csx_high(driver);
    _reset_high(driver);
}

void lcd_power_on(struct lcd_driver_t *driver)
{
    uint8_t pgc_values[15] = { 0x0f, 0x26, 0x24, 0x0b, 0x0e, 0x09, 0x54, 0xa8, 0x46, 0x0c, 0x17, 0x09, 0x0f, 0x07, 0x00 };
    uint8_t ngc_values[15] = { 0x00, 0x19, 0x1b, 0x04, 0x10, 0x07, 0x2a, 0x47, 0x39, 0x03, 0x06, 0x06, 0x30, 0x38, 0x0f };
    
    lcd_swreset(driver);
    _delay_ms(10);
    lcd_display_off(driver);
    lcd_interface_control(driver, 0x01, 0x01, 0x00);
    lcd_power_control_b(driver, 0x81, 0x30);
    lcd_power_on_sequence_control(driver, 0x64, 0x03, 0x12, 0x81);
    lcd_driver_timing_control_a(driver, 0x85, 0x10, 0x78);
    lcd_power_control_a(driver, 0x34, 0x02);
    lcd_pump_ratio_control(driver, 0x20);
    lcd_driver_timing_control_b(driver, 0x00);
    lcd_rgb_interface_signal_control(driver, 0x00);
    lcd_display_inversion_control(driver, 0x00);
    lcd_power_control_1(driver, 0x21);
    lcd_power_control_2(driver, 0x11);
    lcd_vcom_control_1(driver, 0x3F, 0x3C);
    lcd_vcom_control_2(driver, 0xB5);
    // lcd_memory_access_control(driver, MADCTL_MY | MADCTL_BGR);
    lcd_pixel_format_set(driver, DPI_16BIT | DBI_16BIT);
    lcd_frame_rate_control_1(driver, 0x00, 0x1B);
    lcd_enable_3G(driver, 0x00);
    lcd_gamma_set(driver, 0x01);
    lcd_positive_gamma_correction(driver, pgc_values);
    lcd_negative_gamma_correction(driver, ngc_values);
    lcd_entry_mode_set(driver, 0x07);
    lcd_sleep_out(driver);
    _delay_ms(150);
    lcd_display_on(driver);
}

void lcd_reset(struct lcd_driver_t *driver)
{
    _csx_high(driver);
    _reset_low(driver);
    _delay_us(20);
    _reset_high(driver);
}

// Level 1 commands

void lcd_nop(struct lcd_driver_t *driver)
{
    _lcd_command_no_parameter(driver, CMD_NOP);
}

void lcd_swreset(struct lcd_driver_t *driver)
{
    _lcd_command_no_parameter(driver, CMD_SWRESET);
}

uint32_t lcd_read_display_status(struct lcd_driver_t *driver)
{
    uint8_t data[4];
    uint32_t result;
    
    _lcd_command_read_data(driver, CMD_RDDST, data, 4);
    result = (uint32_t)(data[0]) 
            + ((uint32_t)(data[1]) << 8) 
            + ((uint32_t)(data[2]) << 16)
            + ((uint32_t)(data[3]) << 24);
    return result;
}

uint8_t lcd_read_display_power_mode(struct lcd_driver_t *driver)
{
    return _lcd_command_read_single_byte(driver, CMD_RDDPM);
}

uint8_t lcd_read_display_MADCTL(struct lcd_driver_t *driver)
{
    driver->madctl = _lcd_command_read_single_byte(driver, CMD_RDDMADCTL);
    return driver->madctl;
}

uint8_t lcd_read_display_pixel_format(struct lcd_driver_t *driver)
{
    return _lcd_command_read_single_byte(driver, CMD_RDDCOLMOD);
}

uint8_t lcd_read_display_image_format(struct lcd_driver_t *driver)
{
    return _lcd_command_read_single_byte(driver, CMD_RDDIM);
}

uint8_t lcd_read_display_signal_mode(struct lcd_driver_t *driver)
{
    return _lcd_command_read_single_byte(driver, CMD_RDDSM);
}

uint8_t lcd_read_display_self_diagnostic_result(struct lcd_driver_t *driver)
{
    return _lcd_command_read_single_byte(driver, CMD_RDDSDR);
}

void lcd_enter_sleep_mode(struct lcd_driver_t *driver)
{
    _lcd_command_no_parameter(driver, CMD_SPLIN);
}

void lcd_sleep_out(struct lcd_driver_t *driver)
{
    _lcd_command_no_parameter(driver, CMD_SLPOUT);
    _delay_us(5);  // wait for LCD chip to stabilize
}

void lcd_partial_mode_on(struct lcd_driver_t *driver)
{
    _lcd_command_no_parameter(driver, CMD_PTLON);
}

void lcd_normal_display_mode_on(struct lcd_driver_t *driver)
{
    _lcd_command_no_parameter(driver, CMD_NORON);
}

void lcd_display_inversion_off(struct lcd_driver_t *driver)
{
    _lcd_command_no_parameter(driver, CMD_DINVOFF);
}

void lcd_display_inversion_on(struct lcd_driver_t *driver)
{
    _lcd_command_no_parameter(driver, CMD_DINVON);
}

signed short lcd_gamma_set(struct lcd_driver_t *driver, uint8_t gamma_curve)
{   
    uint8_t curve_bit;
    
    // gamma_curve: a value between 1 and 4 incl.
    if (gamma_curve < 1 || gamma_curve > 4) return -1;
    
    curve_bit = 1 << (gamma_curve - 1);
    _lcd_write_command(driver, CMD_GAMSET, &curve_bit, 1);
    return 0;
}

void lcd_display_off(struct lcd_driver_t *driver)
{
    _lcd_command_no_parameter(driver, CMD_DISPOFF);
}

void lcd_display_on(struct lcd_driver_t *driver)
{
    _lcd_command_no_parameter(driver, CMD_DISPON);
}

signed short lcd_column_address_set(struct lcd_driver_t *driver, 
        uint16_t sc, uint16_t ec)
{
    uint8_t data[4];
    
    // SC[15:0] <= EC[15:0]
    if (sc > ec) return -1;
    // SC and EC cannot be out of range
    if (sc > driver->res_x || ec > driver->res_x) return -2;
    
    data[0] = sc >> 8;      // 1st parameter
    data[1] = sc & 0xFF;    // 2nd parameter
    data[2] = ec >> 8;      // 3rd parameter
    data[3] = ec & 0xFF;    // 4th parameter
    _lcd_write_command(driver, CMD_CASET, data, 4);
    return 0;
}

signed short lcd_page_address_set(struct lcd_driver_t *driver,
        uint16_t sp, uint16_t ep)
{
    uint8_t data[4];
    
    // SP[15:0] <= EP[15:0]
    if (sp > ep) return -1;
    // SP and EP cannot be out of range
    if (sp > driver->res_y || ep > driver->res_y) return -2;
    
    data[0] = sp >> 8;      // 1st parameter
    data[1] = sp & 0xFF;    // 2nd parameter
    data[2] = ep >> 8;      // 3rd parameter
    data[3] = ep & 0xFF;    // 4th parameter
    _lcd_write_command(driver, CMD_PASET, data, 4);
    return 0;
}

void lcd_memory_write(struct lcd_driver_t *driver, uint16_t *data, uint32_t size)
{
    _dcx_command(driver);  // transmit a command
    _csx_low(driver);  // select the device
    spi_transfer(CMD_RAMWR);  // transmit the command
    _dcx_data(driver);  // transmit data
    for (uint32_t i = 0; i < size; ++i) {
        spi_transfer(data[i] >> 8);
        spi_transfer(data[i] & 0xFF);
    }
    _csx_high(driver);  // deselect the device
}
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

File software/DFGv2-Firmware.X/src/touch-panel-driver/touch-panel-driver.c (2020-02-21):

#include "touch-panel-driver/touch-panel-driver.h"

#include <inttypes.h>

#include "defs.h"
#include "touch-panel-driver/touch-panel-driver-chip.h"
#include "lcd-driver/lcd-driver.h"
#include "avr_controllers/spi_controller.h"

#include <avr/io.h>

static uint16_t _touch_read_ADC(struct touch_driver_t *, uint8_t);

static uint16_t _touch_multiread(struct touch_driver_t *, uint8_t);

void touch_driver_init(struct touch_driver_t *driver, fbool options)
{
    /* fbool options:
     * bit 0: initialize Master SPI
     * bits 1-7: not used
     */
    // optionally initialize the SPI interface
    if (options & FBOOL0)
        mspi_init(driver->spi);
    
    _tcs_high(driver);
}

uint16_t touch_read_x(struct touch_driver_t *driver)
{
    return ((long)XFAC * _touch_multiread(driver, TP_CMD_RDX)) / 10000 + XOFFSET;
}

uint16_t touch_read_y(struct touch_driver_t *driver)
{
    return ((long)YFAC * _touch_multiread(driver, TP_CMD_RDY)) / 10000 + YOFFSET;
}

short touch_scan(struct touch_driver_t *driver, uint16_t *x, uint16_t *y)
{
    if (!_tirq_state(driver)) {  // touch panel is pressed
        *x = touch_read_x(driver);
        *y = touch_read_y(driver);
        return 1;
    }
    return 0;
}

void touch_get_screen_coordinates(struct lcd_driver_t *lcd_driver,
        uint16_t *x, uint16_t *y)
{
    uint16_t temp;
    enum rotation screen_rotation = lcd_get_rotation(lcd_driver);
    
    switch (screen_rotation) {
    case NORTHEAST:
        *y = lcd_driver->res_y - *y;
        break;
    case SOUTHWEST:
        *x = lcd_driver->res_x - *x;
        break;
    case NORTHWEST:
        *x = lcd_driver->res_x - *x;
        *y = lcd_driver->res_y - *y;
        break;
    case SOUTHEAST:
        break;
    case EASTNORTH:
        temp = *x;
        *x = lcd_driver->res_x - *y;
        *y = temp;
        break;
    case WESTSOUTH:
        temp = *x;
        *x = *y;
        *y = lcd_driver->res_y - temp;
        break;
    case WESTNORTH:
        temp = *x;
        *x = lcd_driver->res_x - *y;
        *y = lcd_driver->res_y - temp;
        break;
    case EASTSOUTH:
        temp = *x;
        *x = *y;
        *y = temp;
        break;
    }
}

static uint16_t _touch_read_ADC(struct touch_driver_t *driver, uint8_t cmd)
{
    uint8_t lsb, msb;
    
    _tcs_low(driver);           // select the device
    spi_transfer(cmd);          // transfer the control byte
    msb = spi_transfer(0x00);   // read the 8 most significant bits
    lsb = spi_transfer(0x00);   // read the 8 least significant bits
    _tcs_high(driver);          // deselect the device
    if (cmd & TP_SERDFR)  // single-ended conversion (12 clk cycles)
        return (msb << 4) | (lsb >> 4);
    else  // ratiometric conversion (13 clk cycles)
        return (msb << 5) | (lsb >> 3);
}

static uint16_t _touch_multiread(struct touch_driver_t *driver, uint8_t cmd)
{
    uint32_t sum = 0;
    
    for (short i = 0; i < SAMPLES; ++i)
        sum += _touch_read_ADC(driver, cmd);
    return sum / SAMPLES;
}

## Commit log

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2019-10-31 [Signal Generator] Draw power supply section of schematic
    The board requires an external power supply which provides the following
    power supply rails:
    - +12VA/-12VA to AGND: for analog circuitry
    - +5VD to DGND: for digital circuitry
    The power supply is connected to the board via a 2x5 pin connector. The
    received power supply rails are additionally smoothed out via some 10uF
    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
    [DDS-system.sch, signal-generator.sch]
2019-10-31 [Signal Generator] Assemble a 16-bit binary counter
    This project's DDS system requires a 16-bit counter in order to iterate
    over each memory self of the selected SRAM IC. However, since there is
    no native 16-bit counter in the 74HC family and the counter itself must
    operate at high frequencies, the project's resultant 16-bit counter is
    made of two 12-bit binary ripple counters which are interconnected via
    some additional logic gates.
    [16-bit-counter.sch, DDS-system.sch, signal-generator.sch]
2019-11-05 [Signal Generator] Design the DDS system
    The project's Direct Digital Synthesis (DDS) system is responsible for
    generating the various user-programmable waveforms, as well as setting
    the generated signal's frequency. The whole system is encapsulated
    within a KiCAD hierarchical sheet. More details on the working operation
    of the DDS system may be found in the (future) documentation of this
    project...soonTM
    [DDS-system.sch, signal-generator.sch]
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2019-11-17 [Signal Generator] Design the output amplifier
    The output amplifier has the capabilities to amplify the weak
    +0.5V/-0.5V signal from the DDS system into a +5V/-5V output signal with
    an optional +5V/-5V DC offset. The amplifier circuit is controlled only
    via the I2C-enabled digital potentiometers (MCP4651 and MCP4551).
    [16-bit-counter.sch, DDS-system.sch, output-circuitry.sch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]
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2019-12-01 [Signal Generator] Design level shifter interface to LCD module
    The LCD breakout board used in this project (MSP3218) is made up of
    three separate components: the LCD and its driver SoC (ILI9341), the
    touch panel and its controller IC (XPT2046), as well as an SD Card
    socket (which can obviously be used to insert an SD card). All three of
    the aforementioned components (ILI9341, XPT2046, SD card) are interfaced
    via the SPI protocol. Unfortunately, each of these components works with
    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
    [level-shifter.sch]
2019-12-01 [Signal Generator] Add LCD module interface components
    Since the LCD breakout board is to be connected to the project's PCB via
    cable wires (i.e. the module won't be soldered directly to the PCB),
    pin connectors have been added to the board. Additionally, the LCD
    backlight is to be adjusted via the added MCP4551 digital potentiometer.
    [TFT-LCD-module-interface-block.sch, level-shifter.sch]
2019-12-01 [Signal Generator] Layout microcontroller and allocate its pins
    The microcontroller is the brains of the function generator system - it
    is responsible for controlling the DDS signal generator system, as well
    as the LCD module which provides the user interface. The specific
    microcontroller used in this project is the ATmega2561-16AU from the
    megaAVR uC family. The reasons I have picked this particular part are
    the following:
    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
    [16-bit-counter.sch, DDS-system.sch, TFT-LCD-module-interface-block.sch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]
2019-12-01 [Signal Generator] Place unused logic gates and logic IC supplies
    Both of these elements can be located on the main project sheet
    ('signal-generator.sch').
    [16-bit-counter.sch, DDS-system.sch, TFT-LCD-module-interface-block.sch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]
2019-12-11 [Signal Generator] Add DAC output conversion stage
    The additional opamp stage is a differential amplifier configuration
    which converts the differential current outputs of the DAC to a singular
    voltage output in the range -0.5V to +0.5V.
    The electrical schematic has overall been finalized with this addition.
    [16-bit-counter.sch, DDS-system.sch, TFT-LCD-module-interface-block.sch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]
2019-12-14 [Signal Generator] Implement +3.3VD line with TC1017 voltage regulator
    Up until now, the +3.3VD line was implemented using the L78L33 linear
    voltage regulator. However, the latter has a dropout voltage of 2V which
    means that the L78L33 cannot output a stable +3.3V from a +5V input.
    To solve the aforementioned problem the TC1017 LDO voltage regulator has
    replaced the L78L33. The former has a low dropout voltage of 180mV (typ.) at
    100mA load current.
    [16-bit-counter.sch, DDS-system.sch, TFT-LCD-module-interface-block.sch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]
2019-12-14 [Signal Generator] Power the LCD module with the +5VD rail
    Previously, the LCD module was powered via the +3.3VD rail. The module itself
    consumes about 90mA and the level shifters may consume >= 50mA in worst
    case scenarios. Looking at the module's (MSP3218) schematic, it can be
    observed that the VCC line is connected to the XC6206 +3.3V LDO voltage
    regulator. Therefore, I have decided to power the module from the +5VD
    supply rail which is external to the board (as opposed to the +3.3VD
    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
    [TFT-LCD-module-interface-block.sch, signal-generator.sch]
2019-12-14 [Signal Generator] Power LCD BL control digital POT from +5VD
    The MCP4551 BL control POT is now powered from +5VD. Its terminals are
    still connected to +3.3VD and GNDD.
    Additionally, a jumper has been added which shorts the +3.3VD rail to
    the LCD BL control on the LCD module (MSP3218). If this connection is
    shorted, the LCD will always be on at full brightness.
    [TFT-LCD-module-interface-block.sch]
2019-12-15 [Signal Generator] Use external reference for DAC. Change MCP23017's I2C address
    The DDS system's DAC (AD9764 or any other from the TxDAC family)
    previously was set up to use its internal 1.2V reference. However, due
    to production tolerances, this reference is quite inaccurate ranging
    from 1.08V to 1.32V (taken from the AD9764's datasheet). Since this
    inaccuracy would greatly affect the generator's precision, I have
    decided to use an external voltage reference. Said reference is
    generated by the TC4061A which produces a very accurate (0.1% deviation)
    1.25V reference.
    Also, the I/O expander's (MCP23017's) I2C address has been changed from
    '0100 111' to '0100 000'.
    [DDS-system.sch, signal-generator.sch]
2019-12-15 [Signal Generator] Minor changes to output amplifier
    1) The 2.2nF capacitor which created a real pole low-pass filter has
    been removed. This is because its cutoff frequency was about 1.4MHz.
    Whilst the generated function as a whole of the digital function
    generator may be considered to have a frequency of 1MHz, the actual
    frequency of the generated signal is in the tens of MHz (e.g.: 64MHz for
    1MHz sine wave with 64 unique points).
    2) The +2.5V voltage reference of the waveform amplification output stage has
    been replaced by the AZ431-A. This is because the latter is much more
    widespread and cheap when compared to the LM4040.
    [output-circuitry.sch]
2019-12-16 [Signal Generator] Annotate electronic components. Associate footprints
    This commit includes the following changes:
    - resistors that must have a low tolerance have had their value marked
    with 1% tolerance in the schematic (e.g. '2k' -> '2k/1%'); all other
    resistors are considered to have 5% tolerance;
    - annotate all schematic components;
    - associate appropriate footprints to every schematic component.
    *Note: I have migrated from KiCad 5.0.2 to KiCad 5.1.5. This is why this
    commit includes backup files of each schematic.
2019-12-20 [Signal Generator] Decouple voltage references with capacitors
    Both the AZ431-A (+2.5V) and the TS4061 (+1.25V) voltage references have
    been decoupled to GND with 100nF capacitors.
    [DDS-system.sch, output-circuitry.sch]
2019-12-21 [Signal Generator] Change LCD backlight control method
    The LCD's backlight was previously intended to be controlled via a
    digital potentiometer. However, a much more elegant solution is to
    control said backlight via PWM.
    Also, removed the level shifter schematic sheet. The level shifters have been
    moved to the TFT module's schematic sheet.
    [16-bit-counter.sch, DDS-system.sch, TFT-LCD-module-interface-block.sch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]
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2019-12-25 [Signal Generator] Layout essential DDS components on PCB
    The most essential components of the DDS system (SRAM, DAC, oscillator,
    first 12-bit counter) have been laid out on the PCB. They have also been
    connected with copper tracks of appropriate width. The reason for this
    early layout and interconnection of these elements is that they are to
    work with very high speed digital signals.
    [signal-generator.kicad_pcb]
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2019-12-28 [Signal Generator] Rework DDS system PCB layout
    The previous layout of the DDS system had its components rather
    awkwardly positioned. Furthermore, it did not take into account the
    distinction of the digital and analog grounds, as well as their star
    ground connection.
    [16-bit-counter.sch, signal-generator.kicad_pcb, signal-generator.sch]
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2019-12-30 [Signal Generator] Rework output circuitry's waveform amplification stage
    The previous design of the waveform amplification stage which utilized
    a digital potentiometer to regulate gain control was flawed due to the
    latter. The digital potentiometer's bandwidth is 2MHz which does not
    fulfill the requirements of the circuit - the output stages may need to
    accommodate for signals with frequencies in the tens of MHz.
    This commit proposes a new design which uses JFET transistors as voltage
    controlled variable resistors. In case this new design is unsuccessful,
    the gain of the waveform amplification output stage may be regulated via
    a mechanical potentiometer.
    [output-circuitry.sch]
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2020-01-02 [Signal Generator] Change via dimensions
    The via dimensions were previously specified in mm whilst now they are
    specified in mils, similar to the track widths. The new dimensions are:
    - 0.8mm / 0.4mm -> 32mil / 16mil;
    - 0.6mm / 0.3mm -> 24mil / 12mil;
    - 20mil / 10mil replace the via which were previously used for digital
    signals.
    [signal-generator.kicad_pcb]
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2020-01-19 [Signal Generator] Change notation of counter reset signals
    ~CMR1 -> CMR1
    ~CMR2 -> CMR2
    [DDS-system.sch, signal-generator.sch]
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2020-01-29 [Firmware] Rework lcd_read_display_status() function
    [lcd-driver.c, main.c]
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2020-02-21 [Firmware] Add UI buttons. Rework graphics library
    [lcd-driver.c, main.c]
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2020-05-20 [Firmware] Fix 10Hz signal values
    [main.c]
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
